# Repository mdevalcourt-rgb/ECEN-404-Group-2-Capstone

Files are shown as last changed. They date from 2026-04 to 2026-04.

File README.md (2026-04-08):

# ESP32-S3 Web Bench Instrument

A self-contained, browser-accessible bench instrument built across 4 custom PCBs — providing a dual-channel oscilloscope, digital multimeter (resistance, current, DC voltage), programmable waveform generator, and adjustable power supply, all served over a self-hosted Wi-Fi access point with no router or installed software required.

## ICs and Their Roles

| IC | Role |
|----|---|
| **ESP32-S3** | Central node — runs the HTTP server, serves the web app from flash, handles all SPI/I²C communication |
| **AD7356** | Dual 12-bit SAR ADC — simultaneous two-channel oscilloscope sampling at 60 kHz (PCB 4) |
| **ADS1115** | 16-bit delta-sigma ADC over I²C — DMM front-end for resistance, current, and DC voltage (PCB 1) |
| **AD9833** | DDS waveform generator over SPI — sine, triangle, and square wave output up to 200 kHz (PCB 3) |
| **MIC24045** | Programmable buck converter over I²C — adjustable output 0.64–5.25 V with live status readback (PCB 2) |

## Built With

- **PlatformIO** on **ESP32-S3** (Arduino framework)
- Vanilla HTML/CSS/JavaScript single-page app embedded in firmware flash
- Python calibration scripts generating empirical piecewise linear fits for all ADC channels

## Documentation

See [README/SETUP_GUIDE.md](README/SETUP_GUIDE.md) for:

- Step-by-step setup instructions for VS Code, PlatformIO, and Claude Code
- Build and flash instructions (USB and OTA)
- Running the web GUI mock server without hardware
- Full web GUI user guide (oscilloscope, DMM, waveform generator, power supply)

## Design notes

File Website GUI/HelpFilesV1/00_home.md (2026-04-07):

# MADAM3 Quick Start

Welcome to the MADAM3 bench instrument. This device provides four tools accessible from the tabs above:

- **Oscilloscope** — View and measure AC waveforms on two channels
- **DMM** — Measure DC voltage, current, and resistance
- **Waveform Generator** — Output sine, square, and triangle waves
- **Power Supply** — Adjustable and fixed voltage rails for your circuits

## Before You Begin

1. Connect a jumper wire from any **GND** pin on the MADAM3 to your breadboard's ground rail. Do this before making any other connections.
2. All measurements and outputs share this common ground. Skipping this step will produce incorrect readings or damage components.

## Pin Layout (Top to Bottom)

| Location | Pins | Purpose |
|---|---|---|
| Top (BNC) | Channel A, Channel B | Oscilloscope inputs |
| Top (header) | GND, GND, Output | Waveform generator |
| Upper header | V\_adj, GND, GND, −5V | Power supply |
| Middle header | NC, NC, Current+, Current−, GND, R out | DMM (current & resistance) |
| Bottom header | NC, NC, V+, R in (+5V), GND, V− | DMM (voltage) / +5V rail (R in) |

## Connecting

1. Power on the MADAM3 and connect to its Wi-Fi access point.
2. The web GUI will open automatically once connected.

Select a tab above to see detailed wiring instructions for each tool.

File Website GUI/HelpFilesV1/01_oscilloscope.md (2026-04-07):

# Oscilloscope

Use the oscilloscope to view and measure **AC signals**. For DC voltage measurements, use the DMM tab instead.

## Pins Used

| Pin | Location | Function |
|---|---|---|
| **Channel A** (BNC) | Top left | Scope input — channel A |
| **Channel B** (BNC) | Top right | Scope input — channel B |

Both channels are sampled simultaneously by the AD7356 dual 12-bit ADC at up to 60 kHz.

## Wiring

Use the **BNC probes** included with your kit.

1. Connect **Channel A** probe to the node you want to observe (typically V\_in).
2. Connect **Channel B** probe to the second node (typically V\_out).
3. Clip the probe ground leads to your breadboard ground rail.

## How to Take Common Measurements

**Amplitude** — Read peak or peak-to-peak voltage directly from the display.

**Time shift (Δt)** — Identify the time difference between matching peaks on Channel A and Channel B. Use this to calculate phase shift:

> Δφ = 360 × Δt × f

**Period (T)** — Measure the time between two consecutive peaks on the same channel. Frequency is:

> f = 1 / T

**Time constant (τ)** — For RC or RL transient circuits, τ is the time for the output to reach 63% of its final value (charging) or decay to 37% (discharging).

**AC RMS Voltage** — The oscilloscope displays the RMS voltage for each channel. Use this when the Lab Manual asks for "AC RMS measurement" or when using the "Logger tool" for AC signals.

## Tips

- Adjust the **timebase** if the waveform looks too compressed or too stretched.
- To save waveform data for your lab report, use the screenshot or export function.

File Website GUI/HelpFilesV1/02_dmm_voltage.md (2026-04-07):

# DMM — DC Voltage

Use this mode to measure DC voltage between two points in your circuit.

## Pins Used

| Pin | Location | Function |
|---|---|---|
| **V+** | Bottom header, pin 3 | Differential voltage input (+) |
| **V−** | Bottom header, pin 6 | Differential voltage input (−) |

V+ and V− are **measurement inputs only** — they do not output any voltage. Do not use these pins to power your circuit. For +5 V power, use the **R in (+5V)** pin on the resistance checker header.

## Wiring

1. Connect **V+** to the higher-potential node in your circuit.
2. Connect **V−** to the lower-potential node (often your ground rail).
3. Read the DC voltage from this screen.

## Measuring Across a Specific Component

To measure the voltage drop across a single resistor, capacitor, or other component, place **V+** on one side and **V−** on the other side of that component — not to ground.

## Verifying Your Power Supply

After setting V\_adj in the Power Supply tab, you should always measure its actual output:

1. Connect **V+** to the V\_adj output wire (where it enters your circuit).
2. Connect **V−** to GND.
3. Record the reading — this is your true supply voltage.

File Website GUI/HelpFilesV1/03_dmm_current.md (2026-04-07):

# DMM — Current

Use this mode to measure DC current through a branch of your circuit. Current is always measured **in series** — the MADAM3 must be inserted into the current path.

## Pins Used

| Pin | Location | Function |
|---|---|---|
| **Current+** | Middle header, pin 3 | Current input — connect to the more positive side |
| **Current−** | Middle header, pin 4 | Current output — connect to the more negative side |

## Wiring

1. **Break** the circuit at the point where you want to measure current. Remove the wire that carries the current you want to measure.
2. Connect **Current+** to the side of the break closer to the positive voltage source.
3. Connect **Current−** to the side of the break closer to ground.
4. The circuit is now complete through the MADAM3's internal current sense path.
5. Read the current from this screen.

## Example

To measure current through a load resistor R\_L:

```
Before:  ... ──── R_L ──── ...
After:   ... ── Current+ ── MADAM3 ── Current− ── R_L ── ...
```

Current flows in through Current+ and out through Current−.

## Safety

- The MADAM3 current measurement supports up to **±5 A**.
- **Never** connect Current+ and Current− directly across a voltage source. This creates a near-short-circuit.
- Only insert the current measurement into a branch that already has a load limiting the current.

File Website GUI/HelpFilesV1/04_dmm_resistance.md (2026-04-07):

# DMM — Resistance

Use this mode to measure the resistance of a component. The component **must be disconnected** from your circuit before measuring.

## Pins Used

| Pin | Location | Function |
|---|---|---|
| **R+** | Bottom header, pin 4 (labeled R in / +5V) | 5 V source — connect to one leg of the component |
| **R out** | Middle header, pin 6 | Sense input — connect to the other leg of the component |

## Wiring

1. **Remove** the component from your breadboard circuit.
2. Connect **R+** to one leg of the component.
3. Connect the other leg to **R out**.
4. Read the resistance from this screen.

## How It Works

The MADAM3 applies 5 V from R+ through the unknown component. The voltage at R out feeds into an internal resistor divider, and the ADS1115 ADC reads the resulting voltage. The software calculates resistance from the voltage ratio.

## What You Can Measure

- Fixed resistors (verify nominal values before building your circuit)
- Potentiometers (measure at minimum and maximum settings)
- Photoresistors (measure under different lighting conditions)
- Thermistors (measure at different temperatures)
- Inductor DC resistance (the winding resistance, not inductance)

## Important

- **Always disconnect** the component first. Measuring resistance in-circuit gives incorrect results because other components provide parallel current paths.
- This mode measures **resistance only**. It cannot measure inductance or capacitance.

## Using R in (+5V) as a Power Rail

The **R in (+5V)** pin also serves as a fixed **+5 V source** for your circuits. When you are not measuring resistance, you can use this pin to power op amp positive rails or logic gate ICs. This is the only +5 V source on the MADAM3 — the V+ and V− pins on the same header are measurement inputs only.

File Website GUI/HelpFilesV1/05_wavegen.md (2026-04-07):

# Waveform Generator

Use the waveform generator to output AC signals into your circuit. This replaces the AD2's Wavegen tool and the function generator in MultiSim simulations.

## Pins Used

| Pin | Location | Function |
|---|---|---|
| **Output** | Top header, pin 3 | Signal output |
| **GND** | Top header, pins 1–2 | Signal return / ground reference |

The output is generated by the AD9833 DDS chip over SPI, capable of sine, triangle, and square waves up to 200 kHz.

## Wiring

1. Connect the **Output** pin to the input node of your circuit (where the Lab Manual shows V\_in or the function generator).
2. Connect one of the adjacent **GND** pins to your breadboard ground rail.

## Settings

Configure these parameters on this screen before enabling the output:

| Parameter | Description |
|---|---|
| **Waveform** | Sine, Square, or Triangle |
| **Frequency** | In Hz — set to the value specified by your lab |
| **Amplitude** | Peak voltage of the signal |
| **Phase** | Phase shift in degrees (0–360°) |

> **Note:** The waveform generator **does not support DC offset**. All waveforms are centered around 0 V. If a lab calls for a DC offset, you will need to add it externally with a bias circuit.

## Common Lab Settings

| Lab | Waveform | Frequency | Amplitude | Notes |
|---|---|---|---|---|
| RC/RL Transients | Square | 20 Hz | 1 V | Lab calls for 1 V offset — requires external bias |
| AC Signals | Sine | 30 Hz | 2 V | Set phase to 50° |
| Op Amp | Sine | 30 Hz | 0.5 V | — |
| Op Amp Integrator | Sine / Square / Triangle | 30 Hz | 0.5 V | Switch waveform type between tests |
| Frequency Response | Sine | 1–1200 Hz | 2 V | Sweep through frequency table |

## Tips

- The Output pin produces the signal relative to the adjacent GND pins. Always use these GND pins — do not rely solely on a GND connection elsewhere on the MADAM3.
- When sweeping frequencies (Lab 6), you may need to adjust the oscilloscope timebase after each frequency change.

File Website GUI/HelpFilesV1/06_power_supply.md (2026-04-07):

# Power Supply

The MADAM3 provides three voltage rails for powering your circuits.

## Pins Used

| Pin | Location | Function |
|---|---|---|
| **V\_adj** | Upper header, pin 1 | Adjustable output: 0.64–5.25 V |
| **−5V** | Upper header, pin 4 | Fixed −5 V output |
| **R in (+5V)** | Bottom header, pin 4 | Fixed +5 V output (shared with resistance checker) |
| **GND** | Multiple locations | Common ground (use any GND pin) |

> **Note:** The **V+** and **V−** pins on the bottom header are DMM measurement inputs only — they do not output any voltage. For a fixed +5 V power source, use **R in (+5V)**.

## V\_adj — Adjustable Power Supply

Controlled by the MIC24045 programmable buck converter over I²C. Set the output voltage on this screen.

**Wiring:**

1. Connect **V\_adj** to the positive rail of your breadboard or directly to the circuit node that needs power.
2. Connect any **GND** pin to the breadboard ground rail.
3. Set the voltage on this screen and enable the output.

**Typical uses:**

- Main 5 V supply for most labs (set to 5.00 V)
- Low-voltage DC input for op amp circuits (e.g., set to 0.5 V)

> Always verify the actual V\_adj output with the DMM after setting it. The Lab Manual requires you to record the measured supply voltage.

## −5V — Fixed Negative Rail

A fixed −5 V output. No configuration needed.

**Wiring:**

1. Connect the **−5V** pin to the circuit node that needs a negative supply (typically the op amp's V− or VEE pin).
2. Ensure **GND** is connected to your breadboard ground rail.

**Used in:** Op amp labs (Labs 3 and 7) as the negative supply rail.

## R in (+5V) — Fixed +5 V Rail

A fixed +5 V output sourced from the resistance measurement circuit. When you are not measuring resistance, this pin provides a clean +5 V rail for your circuits. No configuration needed.

**Wiring:**

1. Connect the **R in (+5V)** pin to the circuit node that needs +5 V.
2. Ensure **GND** is connected to your breadboard ground rail.

**Typical uses:**

- Op amp positive supply when V\_adj is being used as a signal input
- Logic gate IC power (VCC, typically pin 14)

> Do not use this pin for +5 V power and resistance measurement at the same time.

## Op Amp Wiring Summary

Op amp circuits need three simultaneous connections:

| What | DC Input Labs | AC Input Labs |
|---|---|---|
| V\_in (signal) | V\_adj (set low, e.g. 0.5 V) | Waveform Generator Output |
| Op amp + rail | R in (+5V) | V\_adj (set to 5.0 V) |
| Op amp − rail | −5V | −5V |

> **WARNING:** Connecting +5 V and −5 V to the wrong op amp pins will destroy the chip. Double-check polarity before enabling the supply.

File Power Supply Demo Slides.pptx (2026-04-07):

## MADAM3: Power Supply Subsystem

Alex Munoz

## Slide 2

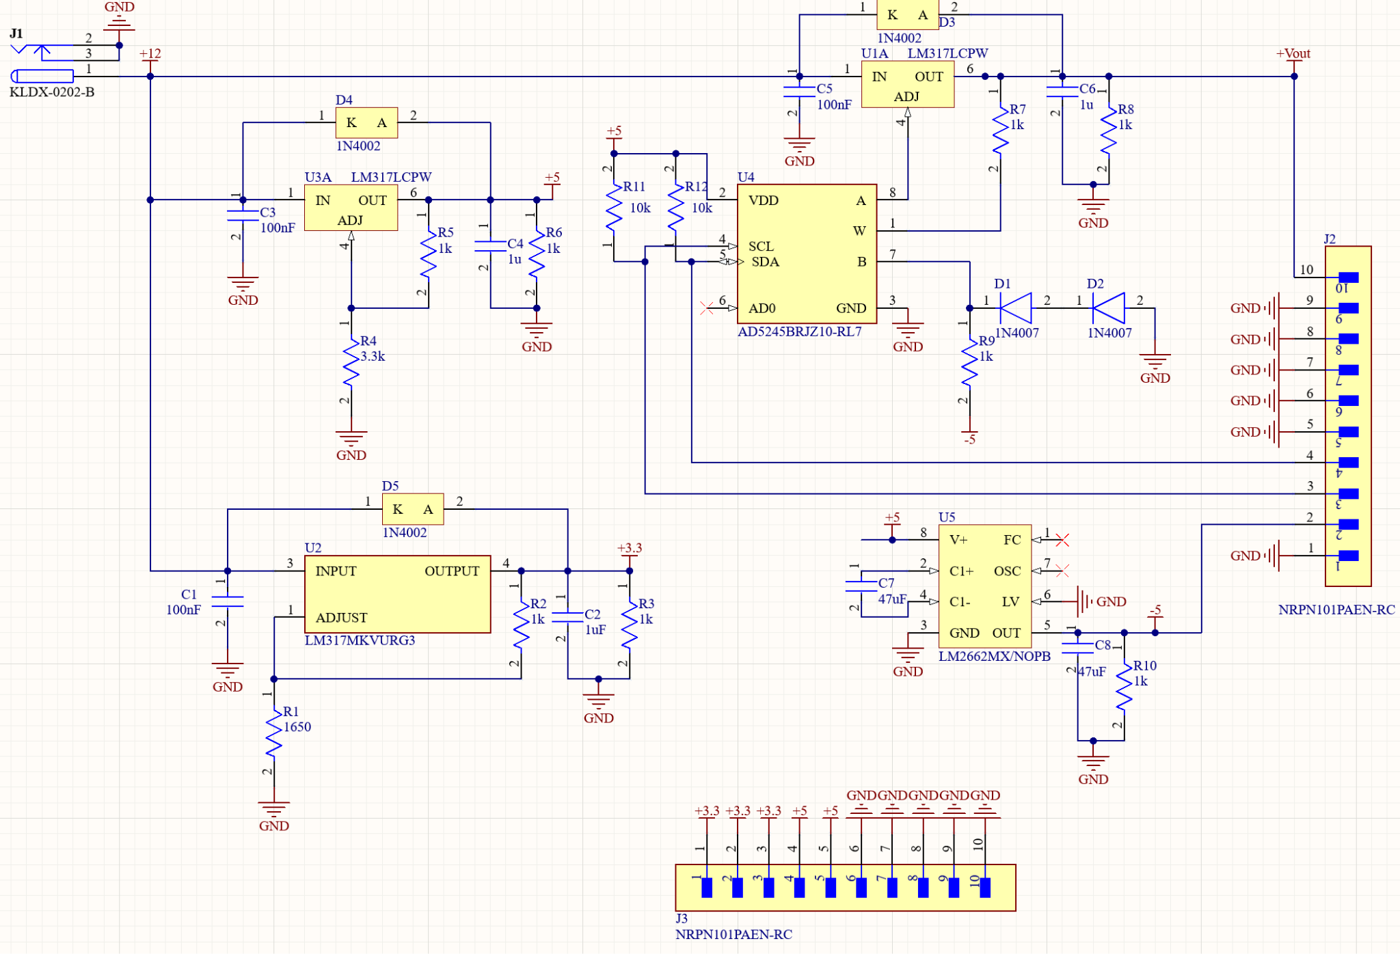
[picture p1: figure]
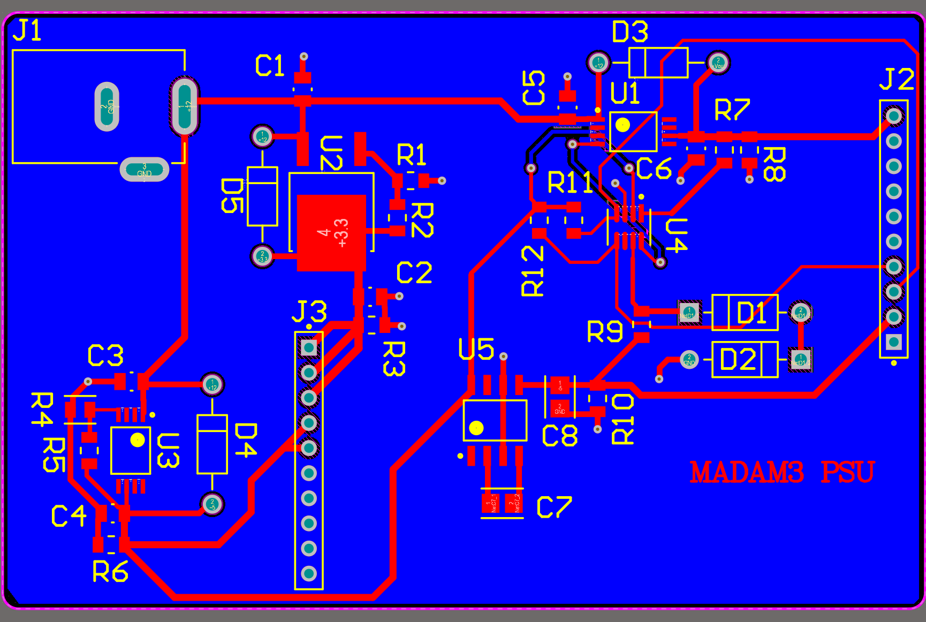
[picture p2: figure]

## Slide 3

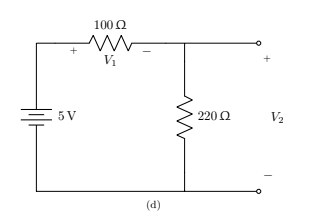
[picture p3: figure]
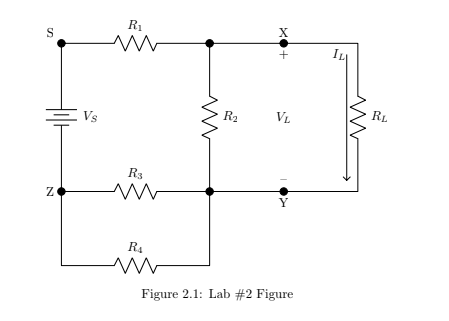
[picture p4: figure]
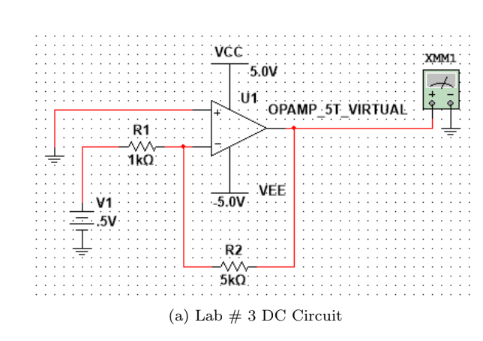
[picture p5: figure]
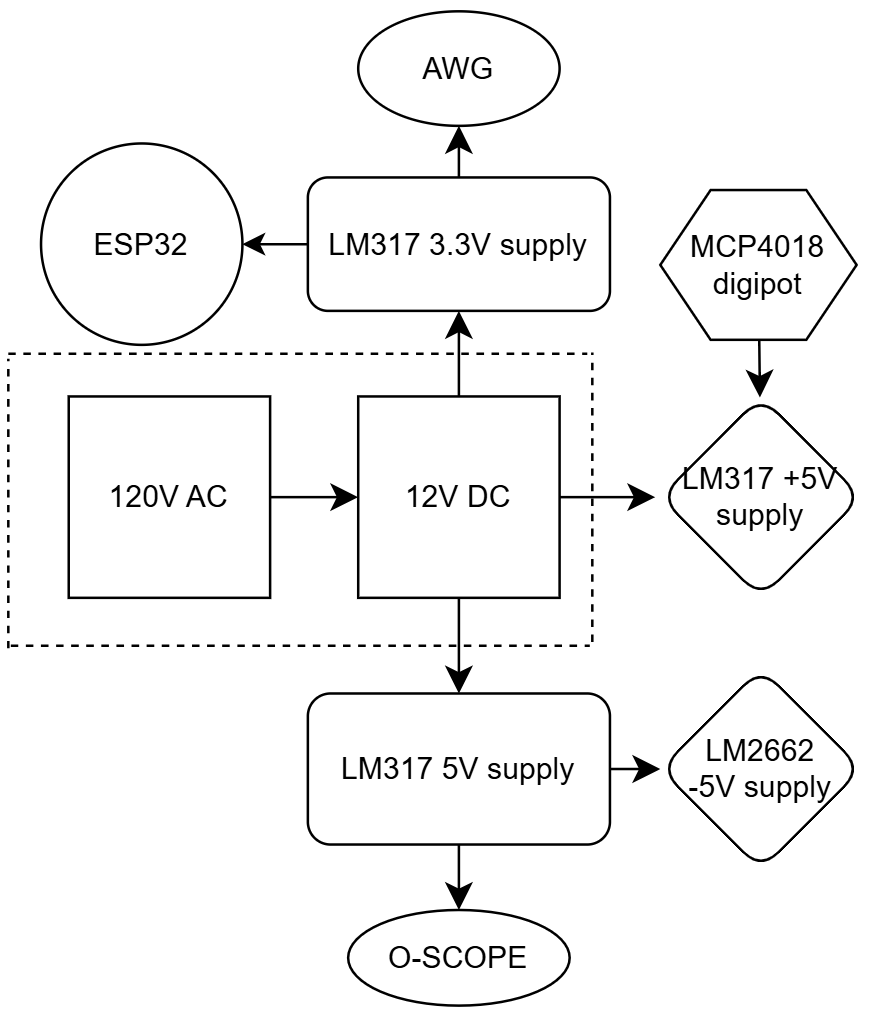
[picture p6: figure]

## Video Demos

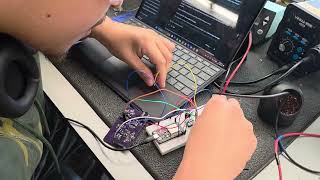
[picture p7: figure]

Analog Outputs

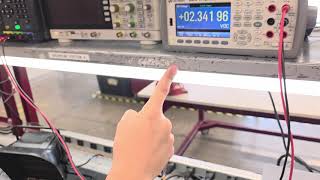
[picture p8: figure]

Digital potentiometer

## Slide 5

3.3V Output Pin Data

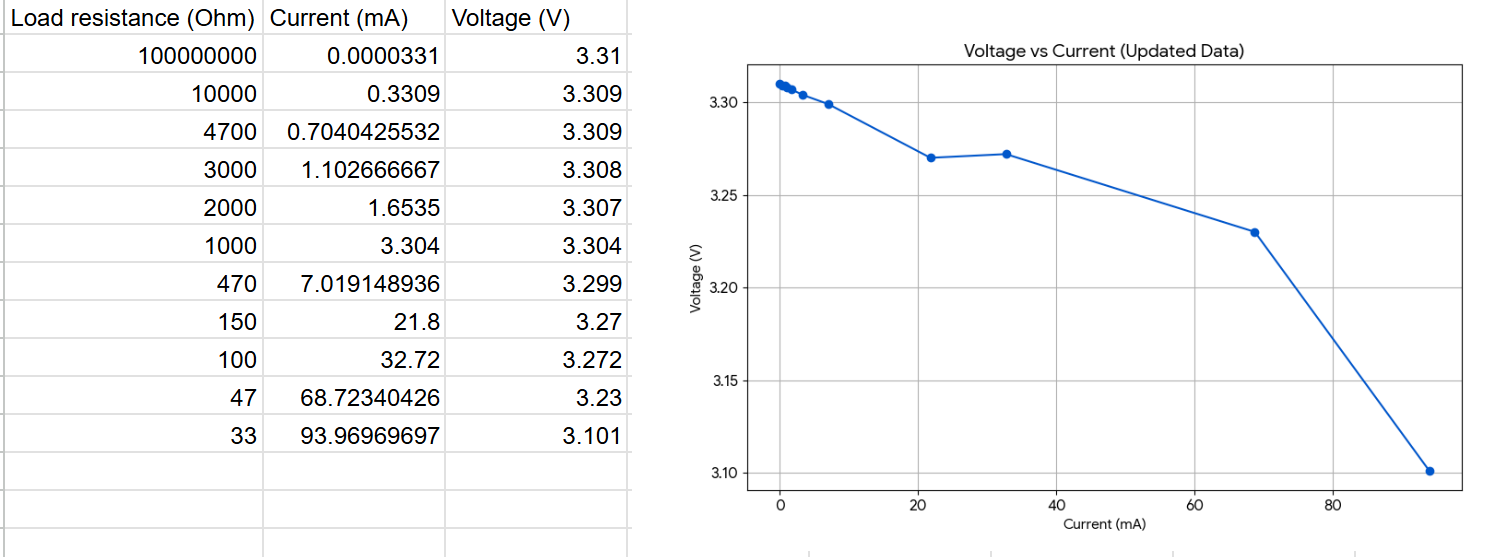
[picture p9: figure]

## 5V Output Pin Data

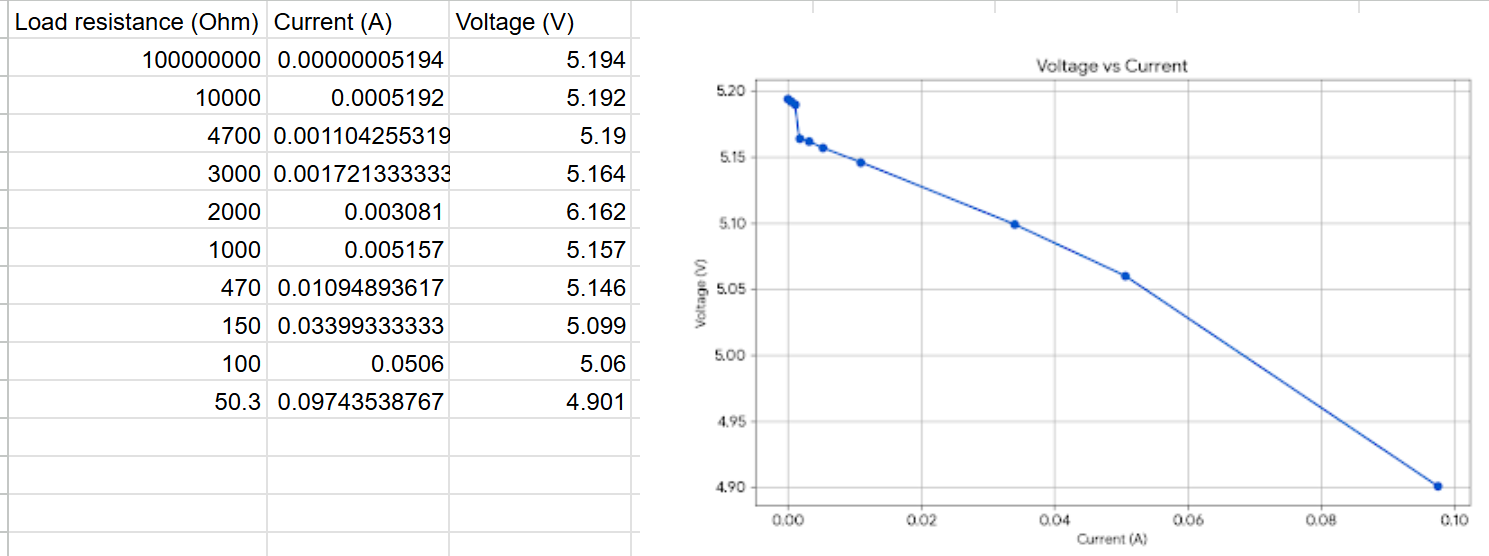
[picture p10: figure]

## -5V Output Pin Data

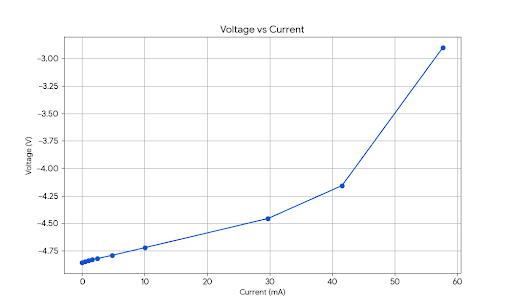
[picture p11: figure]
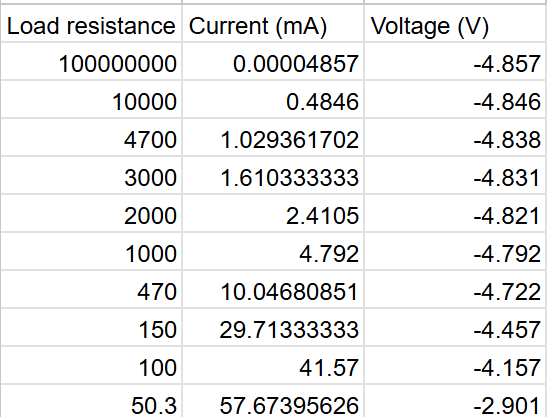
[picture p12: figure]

## Digital Potentiometer Resistance Wiper Sweep

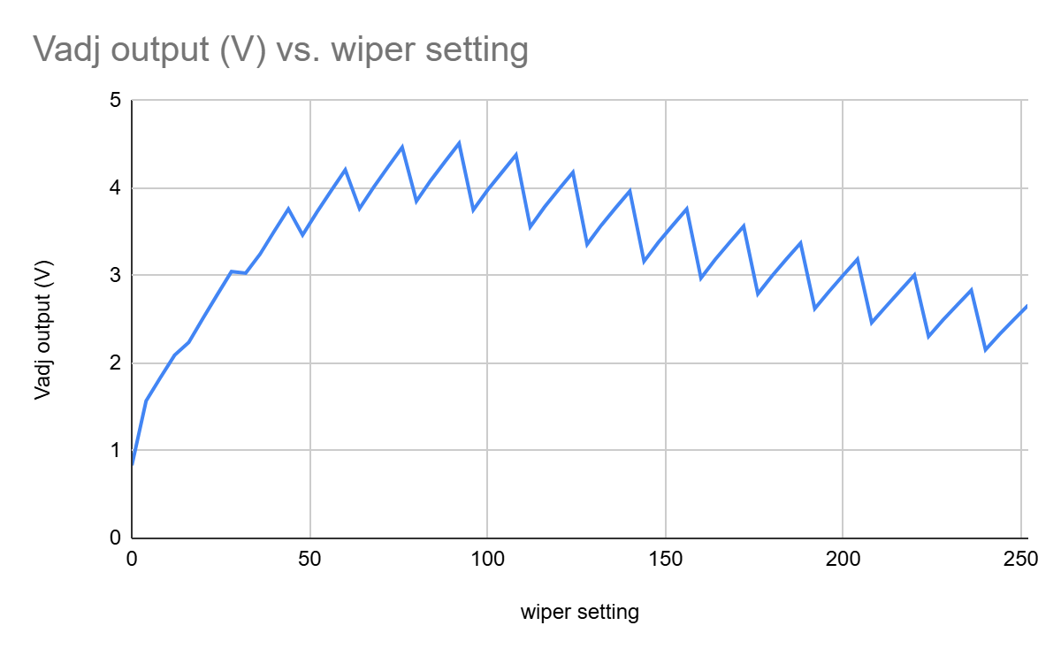
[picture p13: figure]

## Adjustable Voltage Output Pin Data

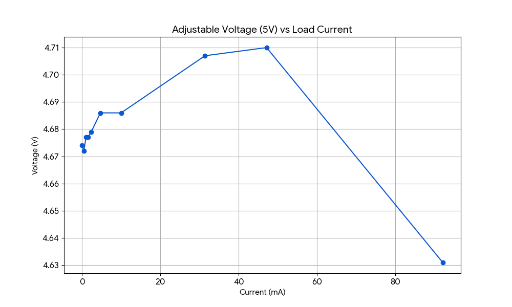
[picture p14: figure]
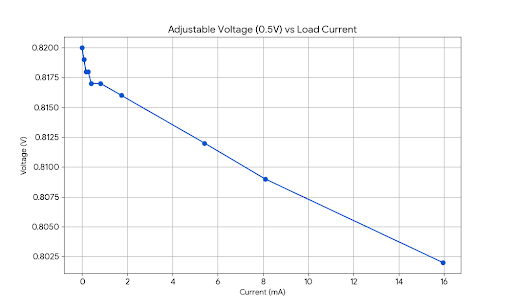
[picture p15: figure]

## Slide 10

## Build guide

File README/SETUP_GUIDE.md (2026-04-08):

# MADAM3 — Complete Setup & User Guide

This guide walks you through everything needed to build, flash, and use the MADAM3 bench instrument firmware — from a clean machine to a running device. It also covers how to run the web GUI locally without hardware using the self-hosted mock server.

---

## Table of Contents

1. [Prerequisites Overview](#1-prerequisites-overview)
2. [Installing VS Code](#2-installing-vs-code)
3. [Installing PlatformIO](#3-installing-platformio)
4. [Installing Claude Code (optional)](#4-installing-claude-code-optional)
5. [Opening the Project](#5-opening-the-project)
6. [Building and Flashing the Firmware](#6-building-and-flashing-the-firmware)
7. [Over-the-Air (OTA) Updates](#7-over-the-air-ota-updates)
8. [Web GUI Self-Hosted Mock Server](#8-web-gui-self-hosted-mock-server)
9. [Web GUI User Guide](#9-web-gui-user-guide)

---

## 1. Prerequisites Overview

You will need the following installed before starting:

| Tool | Purpose | Required |
|---|---|---|
| **VS Code** | Code editor | Yes |
| **PlatformIO** | Firmware build system (VS Code extension) | Yes |
| **Python 3.8+** | Running the mock dev server | For mock server only |
| **Claude Code** | AI-assisted coding in the terminal | Optional |

---

## 2. Installing VS Code

1. Go to [https://code.visualstudio.com/](https://code.visualstudio.com/) and download the installer for your OS.
2. Run the installer and accept all defaults.
3. Launch VS Code once the installation completes.

---

## 3. Installing PlatformIO

PlatformIO is the build system used for this project. It runs as a VS Code extension.

1. In VS Code, click the **Extensions** icon in the left sidebar (or press `Ctrl+Shift+X`).
2. Search for **PlatformIO IDE**.
3. Click **Install** on the result published by *PlatformIO*.
4. Wait for the installation to finish — this may take a few minutes as it downloads the PlatformIO core tools.
5. When prompted, **reload VS Code** (or restart it manually).

After reloading, you will see the PlatformIO alien-head icon in the left sidebar. Click it to confirm PlatformIO is active.

> **Note:** PlatformIO automatically installs the ESP32 toolchain and all required libraries the first time you build the project. You do not need to install them manually.

---

## 4. Installing Claude Code (optional)

Claude Code is a command-line AI assistant for working with code. It is not required to build or flash the firmware, but it is useful for understanding and modifying the codebase.

### Prerequisites for Claude Code

- **Node.js 18 or later** — download from [https://nodejs.org/](https://nodejs.org/) and install using the LTS (Long Term Support) version.

### Installing Claude Code

Open a terminal (on Windows: press `Win+R`, type `cmd`, press Enter) and run:

```bash
npm install -g @anthropic-ai/claude-code
```

### First-time login

```bash
claude
```

On the first run, Claude Code will open a browser window and prompt you to log in with your Anthropic account. Follow the on-screen steps to authenticate.

### Using Claude Code in this project

1. Open a terminal inside VS Code (`Ctrl+`` ` ``).
2. Navigate to the project folder:
   ```bash
   cd "Website GUI"
   ```
3. Start Claude Code:
   ```bash
   claude
   ```
4. You can now ask questions about the firmware or request changes. For example:
   - *"Explain how the HTTP server routes are set up"*
   - *"What does the ADS1115 sampler do?"*
   - *"Add a new API endpoint that returns the chip temperature"*

---

## 5. Opening the Project

The firmware project lives in the `Website GUI/` subfolder.

1. In VS Code, go to **File → Open Folder**.
2. Navigate to and select the `Website GUI` folder inside this repository.
3. VS Code will detect the `platformio.ini` file and activate PlatformIO automatically.

You should see two environments listed in the PlatformIO sidebar:
- `esp32s3usbotg` — used for the first flash over USB
- `esp32s3usbotg-ota` — used for subsequent wireless updates

---

## 6. Building and Flashing the Firmware

### First flash (USB cable required)

1. Connect the ESP32-S3 to your computer with a USB cable.

2. In the VS Code PlatformIO sidebar, expand **esp32s3usbotg** and click **Upload**, or use the toolbar at the bottom of VS Code and click the right-arrow (→) upload button.

   Alternatively, open the PlatformIO terminal (`Ctrl+`` ` ```) and run:
   ```bash
   pio run -e esp32s3usbotg -t upload
   ```

3. PlatformIO will:
   - Download the ESP32 toolchain on first run (this takes a few minutes)
   - Compile all source files
   - Flash the binary to the board

4. Once flashing completes, open the serial monitor to confirm startup:
   - Click the plug icon at the bottom of VS Code, or run:
     ```bash
     pio device monitor
     ```
   - You should see output including `HTTP server started` and the AP IP address.

5. On your phone or laptop, connect to the Wi-Fi access point:
   - **SSID:** `ESP32-Oscilloscope`
   - **Password:** `scopeview123`

6. Open a browser and navigate to `http://192.168.4.1/`. The web GUI will load automatically (captive portal redirects handle this on most devices).

### Serial monitor commands

Once the serial monitor is open, you can type:

| Command | Effect |
|---|---|
| `log` | Replay all startup messages (useful if the monitor was not open during boot) |

---

## 7. Over-the-Air (OTA) Updates

After the first USB flash, you can update the firmware wirelessly without a cable.

1. Connect your computer to the `ESP32-Oscilloscope` Wi-Fi network (password: `scopeview123`).

2. In PlatformIO, select the **esp32s3usbotg-ota** environment and click **Upload**, or run:
   ```bash
   pio run -e esp32s3usbotg-ota -t upload
   ```

3. PlatformIO connects to `192.168.4.1` using the OTA password `scopeota123` and uploads the new firmware wirelessly.

> **Important:** Your computer must be connected to the ESP32's Wi-Fi network — not your normal internet router — when performing an OTA update.

---

## 8. Web GUI Self-Hosted Mock Server

The mock server lets you run and develop the web GUI on your computer without any hardware. It extracts the HTML/CSS/JavaScript directly from `src/WebContent.cpp` and serves it locally, while providing simulated API responses for all instrument endpoints.

### Requirements

- Python 3.8 or later. Check by running:
  ```bash
  python --version
  ```
  If Python is not installed, download it from [https://www.python.org/downloads/](https://www.python.org/downloads/). During installation, check **"Add Python to PATH"**.

- No additional Python packages are required — the server uses only the standard library.

### Starting the server

1. Open a terminal in the `Website GUI/` folder.

   In VS Code: open the integrated terminal (`Ctrl+`` ` ```) and run:
   ```bash
   cd "Website GUI"
   ```

2. Start the server:
   ```bash
   python mock_server.py
   ```

3. You will see:
   ```
     MADAM3 dev server
     Open → http://localhost:8080/
     HTML from: ...\Website GUI\src\WebContent.cpp
     Ctrl+C to stop.
   ```

4. Open `http://localhost:8080/` in your browser.

### What the mock server simulates

| Endpoint | Method | Description |
|---|---|---|
| `/` | GET | Serves the full web GUI |
| `/adc/burst` | GET | Returns simulated dual-channel oscilloscope data |
| `/ads/measure` | GET | Returns simulated DMM readings (voltage, current, resistance) |
| `/control-state` | GET | Returns current waveform generator and power supply state |
| `/waveform` | POST | Updates waveform generator settings |
| `/power` | POST | Updates power supply voltage |
| `/dev/config` | GET/POST | Reads or updates the simulated signal configuration panel |

### Using the developer configuration panel

The mock server exposes a **Dev Config** panel inside the web GUI (visible only when running against the mock server). This panel lets you control the simulated signals in real time:

**Oscilloscope channels:**

| Setting | Description |
|---|---|
| Shape | Waveform shape for each channel: `sine`, `square`, or `triangle` |
| Frequency | Signal frequency in Hz |
| Amplitude | Peak voltage (up to ±2 V) |
| Phase | Phase offset in degrees (useful for testing phase-shift displays) |
| Noise | Gaussian noise level in volts added to both channels |

**DMM:**

| Setting | Description |
|---|---|
| Voltage | Simulated DC voltage in volts |
| Current | Simulated current in amps |
| Resistance | Simulated resistance in ohms |

**Power supply:**

| Setting | Description |
|---|---|
| Voltage | Simulated V_adj output voltage |

Changes take effect immediately — the next data poll from the GUI picks up the new values.

### Stopping the server

Press `Ctrl+C` in the terminal where the server is running.

---

## 9. Web GUI User Guide

The web GUI is a single-page application accessible from any browser connected to the MADAM3's Wi-Fi. It provides four instrument tabs.

### Connecting to the device

1. Power on the MADAM3.
2. On your device (phone, laptop, tablet), open Wi-Fi settings and connect to:
   - **SSID:** `ESP32-Oscilloscope`
   - **Password:** `scopeview123`
3. A captive portal should open the GUI automatically. If it does not, open a browser and go to `http://192.168.4.1/`.

---

### Oscilloscope

The oscilloscope displays real-time AC waveforms on two channels, sampled simultaneously by the AD7356 at up to 60 kHz.

**Connections:**

| Pin | Location | Function |
|-----|---|---|
| Channel A (BNC) | Top left | Scope input — channel A |
| Channel B (BNC) | Top right | Scope input — channel B |

**How to use:**

1. Clip the BNC probe ground leads to your circuit's ground rail.
2. Touch the probe tip to the node you want to observe.
3. Adjust the **timebase** slider if the waveform is too compressed or stretched.
4. Read measurements directly from the display:
   - **Peak-to-peak voltage** — amplitude of the signal
   - **RMS voltage** — useful for AC power calculations and lab reports
   - **Period / Frequency** — time between consecutive peaks

**Common measurements:**

- **Phase shift (Δφ):** Measure the time difference (Δt) between matching peaks on channel A and B. `Δφ = 360 × Δt × f`
- **Time constant (τ):** For RC/RL circuits, τ is the time to reach 63% of final value when charging, or 37% when discharging.

> Use the oscilloscope for AC signals. For DC voltage, use the DMM tab.

---

### DMM — DC Voltage

Measures DC voltage between two points.

**Connections:**

| Pin | Location | Function |
|-----|---|---|
| V+ | Bottom header, pin 3 | Positive measurement input |
| V− | Bottom header, pin 6 | Negative measurement input |

**How to use:**

1. Connect **V+** to the higher-potential node.
2. Connect **V−** to the lower-potential node (often ground).
3. Read the DC voltage from the screen.

To measure voltage across a specific component, place V+ and V− on either side of it — not to ground.

> V+ and V− are measurement inputs only. Do not use them to power your circuit.

---

### DMM — Current

Measures DC current through a branch. The MADAM3 must be inserted **in series** into the current path.

**Connections:**

| Pin | Location | Function |
|-----|---|---|
| Current+ | Middle header, pin 3 | Current input (connect to positive side) |
| Current− | Middle header, pin 4 | Current output (connect to negative side) |

**How to use:**

1. Break the circuit at the point where you want to measure current.
2. Connect **Current+** to the side closer to the positive supply.
3. Connect **Current−** to the side closer to ground/load.
4. Read the current from the screen.

**Safety:** Maximum supported current is ±5 A. Never connect Current+ and Current− directly across a voltage source — this creates a near-short-circuit.

---

### DMM — Resistance

Measures component resistance. The component **must be removed from your circuit** before measuring.

**Connections:**

| Pin | Location | Function |
|-----|---|---|
| R+ (R in / +5V) | Bottom header, pin 4 | 5 V source — connect to one leg |
| R out | Middle header, pin 6 | Sense input — connect to other leg |

**How to use:**

1. Remove the component from your circuit.
2. Connect **R+** to one leg of the component.
3. Connect the other leg to **R out**.
4. Read the resistance from the screen.

**Measurable components:** fixed resistors, potentiometers, photoresistors, thermistors, inductor DC winding resistance.

> Measuring resistance in-circuit gives incorrect results because other components create parallel current paths.

The **R in (+5V)** pin doubles as a fixed +5 V power rail when you are not measuring resistance.

---

### Waveform Generator

Outputs AC signals from the AD9833 DDS chip.

**Connections:**

| Pin | Location | Function |
|-----|---|---|
| Output | Top header, pin 3 | Signal output |
| GND | Top header, pins 1–2 | Signal return / ground reference |

**How to use:**

1. Connect **Output** to the input node of your circuit (V_in).
2. Connect an adjacent **GND** pin to your circuit's ground rail.
3. Configure the signal parameters on the Waveform Generator tab:

| Parameter | Description | Range |
|---|---|---|
| Waveform | Shape: Sine, Square, or Triangle | — |
| Frequency | Signal frequency | Up to 200 kHz |
| Amplitude | Peak voltage of the signal | — |
| Phase | Phase shift | 0–360° |

4. Enable the output.

> The waveform generator outputs signals centered at 0 V — it does not support a built-in DC offset. Add an external bias circuit if a lab requires a DC offset.

**Common lab settings:**

| Lab type | Waveform | Frequency | Amplitude |
|---|---|---|---|
| RC/RL Transients | Square | 20 Hz | 1 V |
| AC Signals | Sine | 30 Hz | 2 V |
| Op Amp | Sine | 30 Hz | 0.5 V |
| Frequency Response | Sine | 1–1200 Hz (sweep) | 2 V |

---

### Power Supply

Provides three voltage rails for your circuits, controlled by the MIC24045 programmable buck converter.

**Available rails:**

| Rail | Pin | Value | Notes |
|---|-----|---|---|
| V_adj | Upper header, pin 1 | 0.64–5.25 V adjustable | Set on this screen |
| −5V | Upper header, pin 4 | Fixed −5 V | Always on |
| +5V (R in) | Bottom header, pin 4 | Fixed +5 V | Shared with resistance checker |

**How to use V_adj:**

1. Set the desired voltage on the Power Supply tab.
2. Connect **V_adj** to the positive rail of your circuit.
3. Connect any **GND** pin to the ground rail.
4. Enable the output.
5. Verify the actual output voltage with the DMM tab — always record the measured value, not just the set value.

**Op amp wiring summary:**

| Signal | DC input labs | AC input labs |
|---|---|---|
| V_in (signal) | V_adj (set low, e.g. 0.5 V) | Waveform Generator Output |
| Op amp + rail | R in (+5V) | V_adj (set to 5.0 V) |
| Op amp − rail | −5V | −5V |

> **WARNING:** Connecting +5 V and −5 V to the wrong op amp pins will destroy the chip. Double-check polarity before enabling any supply.

---

### General Tips

- Always connect a **GND** pin to your breadboard ground rail before making any other connections.
- All measurements and outputs share a common ground.
- When the Wi-Fi indicator in the GUI shows disconnected, the browser has lost contact with the ESP32. Reload the page or reconnect to the `ESP32-Oscilloscope` network.
- The serial monitor (`pio device monitor`, 115200 baud) shows live diagnostic output. Type `log` to replay startup messages.

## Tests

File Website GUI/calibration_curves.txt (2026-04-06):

============================================================
  AIN0  — Resistance (Ohm)
============================================================
  Calibration points: 5

  Raw data:
            bits       user value
    ------------   --------------
           393.0    102070.000000
          3585.8      9826.000000
         16150.3       983.500000
         25270.7        98.019997
         26789.2         9.822000

  Fit type  :  inverse   y = A / x  -  B
  A         :  40711273.7439
  B         :  1521.7255
  OC bits   :  0.1  (reads <= this → O.C.)
  R²        :  1.000000
  RMSE      :  9.9222  Ohm  (before correction)

  Piecewise correction table:
          estimate   error (overcounting)
    --------------   --------------------
           -2.0357             -11.857701
           89.2815              -8.738523
          999.0496             +15.549586
         9831.7448              +5.744792
       102069.3018              -0.698154

============================================================
  AIN1  — Current (A)
============================================================
  Calibration points: 6

  Raw data:
            bits       user value
    ------------   --------------
         19698.4         0.499000
         19850.4         0.400000
         20005.4         0.300000
         20160.2         0.200000
         20311.6         0.100000
         20444.8         0.010000

  Fit type  :  linear    y = M * x  +  B
  M         :  -0.00065354
  B         :  13.37348381
  R²        :  0.999939
  RMSE      :  0.001318  A  (before correction)

  Piecewise correction table:
          estimate   error (overcounting)
    --------------   --------------------
          0.012088              +0.002088
          0.099139              -0.000861
          0.198084              -0.001916
          0.299252              -0.000748
          0.400550              +0.000550
          0.499887              +0.000887

============================================================
  AIN2-3 Differential — DC Voltage (V)
============================================================
  Calibration points: 6

  Raw data:
            bits       user value
    ------------   --------------
             2.2         0.001000
          4751.0         0.999000
          9500.0         1.998000
         14251.0         2.998000
         19002.2         3.997000
         23751.9         4.996000

  Fit type  :  linear    y = M * x  +  B
  M         :  0.00021034
  B         :  0.00013654
  R²        :  1.000000
  RMSE      :  0.000316  V  (before correction)

  Piecewise correction table:
          estimate   error (overcounting)
    --------------   --------------------
          0.000599              -0.000401
          0.999443              +0.000443
          1.998328              +0.000328
          2.997634              -0.000366
          3.996982              -0.000018
          4.996015              +0.000015

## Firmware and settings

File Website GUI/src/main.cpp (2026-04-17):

#include <Arduino.h>

#include "Ad7356Sampler.h"
#include "Ad9833Driver.h"
#include "Ads1115Sampler.h"
#include "HttpServer.h"
#include "Mic24045.h"
#include "StartupLog.h"
#include "CaptivePortal.h"
#include "OtaUpdater.h"
#include "WiFiConnector.h"

#if __has_include("secrets.h")
  #include "secrets.h"
#else
  #error "Missing include/secrets.h — copy include/secrets.example.h to include/secrets.h and fill in the credentials."
#endif

Ad7356Sampler  adcSampler;
Ad9833Driver   wavegen;
Ads1115Sampler adsSampler;
Mic24045       mic;

// ---------------------------------------------------------------------------

void printAdcInfo() {
  String line = "ADC channels: ";
  for (size_t i = 0; i < adcSampler.channelCount(); ++i) {
    line += adcSampler.label(i);
    if (i + 1 < adcSampler.channelCount()) line += ", ";
  }
  logln(line.c_str());
}

void setup() {
  Serial.begin(115200);
  // Startup messages are buffered so they are never lost even if the serial
  // monitor is not open yet.  Type "log" in the serial monitor to replay them.

  logln("[SETUP] Serial ready");

  logln("[SETUP] adcSampler.begin()");
  adcSampler.begin();
  logln("[SETUP] adcSampler.begin() done");
  adcSampler.diagnose();

  logln("[SETUP] wavegen.begin()");
  wavegen.begin();
  logln("[SETUP] wavegen.begin() done");

  // Probe both I²C chips in parallel for up to 2 seconds.
  bool micOk = false;
  bool adsOk = false;
  const uint32_t initDeadline = millis() + 2000;
  logln("[SETUP] entering I2C init loop (2 s deadline)");
  while (millis() < initDeadline) {
    logf("[SETUP] tick t=%lu ms  micOk=%d adsOk=%d\n",
         millis(), micOk, adsOk);
    if (!micOk) micOk = mic.begin();
    if (!adsOk) adsOk = adsSampler.begin();
    if (micOk && adsOk) break;
    yield();
    delay(100);
  }
  logln("[SETUP] I2C init loop done");
  logln(micOk ? "MIC24045 initialized." : "MIC24045 init failed.");
  logln(adsOk ? "ADS1115 initialized."  : "ADS1115 init failed. Check wiring/address.");

  logln("[SETUP] startAccessPoint()");
  startAccessPoint(AP_SSID, AP_PASSWORD);
  logln("[SETUP] startAccessPoint() done");

  logln("[SETUP] setupCaptivePortal()");
  setupCaptivePortal();
  logln("[SETUP] setupCaptivePortal() done");

  logln("[SETUP] setupOTA()");
  setupOTA(OTA_HOSTNAME, OTA_PASSWORD);
  logln("[SETUP] setupOTA() done");

  logln("[SETUP] setupServerRoutes()");
  setupServerRoutes(adcSampler, adsSampler, mic, wavegen);
  logln("[SETUP] httpServer().begin()");
  httpServer().begin();

  logln("HTTP server started. Open the IP above in a browser.");
  printAdcInfo();
  logln("[SETUP] setup() complete");
  Serial.println("Type \"log\" to replay startup messages.");
}

// ---------------------------------------------------------------------------
// Serial command handler
// ---------------------------------------------------------------------------
static String serialBuf;

static void handleSerial() {
  while (Serial.available()) {
    char c = Serial.read();
    if (c == '\n' || c == '\r') {
      serialBuf.trim();
      if (serialBuf.equalsIgnoreCase("log")) {
        printStartupLog();
      } else if (serialBuf.length() > 0) {
        Serial.printf("Unknown command: \"%s\". Available: log\n",
                      serialBuf.c_str());
      }
      serialBuf = "";
    } else {
      serialBuf += c;
    }
  }
}

void loop() {
  handleCaptivePortal();
  handleOTA();
  handleSerial();
  httpServer().handleClient();
}

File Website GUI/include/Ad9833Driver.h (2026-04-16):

#pragma once

#include <Arduino.h>
#include <SPI.h>

// AD9833 DDS waveform generator + MCP41010 digital potentiometer amplitude control.
//
// Pin assignments (ESP32-S3, avoids USB GPIO19-20, flash GPIO26-32,
// AD7356 GPIO10-13, ADS1115/MIC24045 I²C GPIO5-6):
//   SPI SCK    → GPIO 18
//   SPI MOSI   → GPIO 14
//   AD9833 /FSYNC (CS) → GPIO 15   (SPI_MODE2)
//   MCP41010   CS      → GPIO 16   (SPI_MODE0)
//
// Call begin() once in setup(). Then call apply() whenever any parameter
// changes — it updates frequency, waveform shape, and amplitude atomically.
class Ad9833Driver {
 public:
  Ad9833Driver() = default;
  void begin();

  // Apply all parameters in one call.
  // mode        : "sine" | "triangle" | "square"
  // hz          : 0.1 – 12.5 MHz (AD9833 limit with 25 MHz MCLK)
  // targetV     : desired output voltage (V); mapped to digipot via calibrated fit
  // phaseDeg    : phase offset in degrees (0–360), written to PHASE0 register
  void apply(const String& mode, float hz, float targetV, float phaseDeg = 0.0f);

  // Write a raw 8-bit wiper value (0–255) directly to the MCP41010,
  // bypassing the calibrated fit entirely.
  void setAmplitudeRaw(uint8_t potValue);

 private:
  // SPI pins
  static constexpr uint8_t kSckPin    = 18;
  static constexpr uint8_t kMosiPin   = 14;
  static constexpr uint8_t kFsyncPin  = 15;  // AD9833 chip-select (active LOW)
  static constexpr uint8_t kPotCsPin  = 16;  // MCP41010 chip-select (active LOW)

  // AD9833 master clock (25 MHz oscillator)
  static constexpr float kMclkHz = 25000000.0f;

  // AD9833 control words (B28 mode, RESET cleared)
  static constexpr uint16_t kCtrlSine     = 0x2000;
  static constexpr uint16_t kCtrlTriangle = 0x2002;
  static constexpr uint16_t kCtrlSquare   = 0x2028;

  // AD9833 phase register write prefix — DB15:DB14=11, DB13=0 → PHASE0
  static constexpr uint16_t kPhase0Write = 0xC000;

  // MCP41010 amplitude calibration — least-squares fit through three
  // confirmed hardware measurements: (0.5 V → 65), (1.0 V → 165), (1.7 V → 255).
  //   pot = kCalSlope * targetV + kCalOffset   (clamped to [0, 255])
  static constexpr float kCalSlope  = 156.422f;
  static constexpr float kCalOffset = -5.183f;

  void writeAD9833(uint16_t data);
  void setFrequency(float hz);
  void setPhase(float degrees);
  void setWaveformShape(const String& mode);
};

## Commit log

2026-01-15 Create power supply
2026-01-15 Update power supply
2026-01-15 Add files via upload
    Schematic and pcb layout files from 403
    [dualPSUpcb.PcbDoc, powersupply1.SchDoc]
2026-04-06 Initial commit: PlatformIO firmware for AD7356, AD9833, ADS1115, MIC24045
    [gui_workflow_slides.csv]
2026-04-06 Removed local organizational files
    [gui_workflow_slides.csv]
2026-04-07 Moving web gui into own folder
    [gui_workflow_slides.csv]
2026-04-07 moving R1 PSU files into Power Supply folder
    [dualPSUpcb.PcbDoc, powersupply1.SchDoc]
2026-04-07 moving R1 PSU files into Power Supply folder, 2nd try
    [dualPSUpcb.PcbDoc, powersupply1.SchDoc]
2026-04-07 changes to read negative voltage, slow reading mode, and over the air updates
2026-04-16 Major UI rework, added bode plot generator
    [Ad7356Sampler.cpp, Ad7356Sampler.h, Ad9833Driver.cpp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]
2026-04-16 Polarity fix to bode plot
    [HttpServer.cpp]
2026-04-17 Added cyber fixes for known vulns
    [main.cpp]
2026-04-28 Create I2C_BUCK_CODE
